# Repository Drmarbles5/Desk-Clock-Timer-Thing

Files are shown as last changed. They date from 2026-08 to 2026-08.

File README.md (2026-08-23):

# Desk Clock Timer

Compact STM32-controlled Bluetooth desk clock powered over USB-C with a [4200 mAh lithium battery](https://www.amazon.ca/4200mah-Rechargeable-Lithium-Replacement-Electronic/dp/B095BP7V1D?th=1) for portability. It connects to Windows/Linux over USB and Bluetooth Low Energy (BLE) for time sync, alarm setup, and media data, and drives a [7.5 inch E-ink display](https://www.waveshare.com/product/7.5inch-e-paper-b.htm) to show the clock, Pomodoro timer, and live Spotify/media information.

<br>
<div align="left">
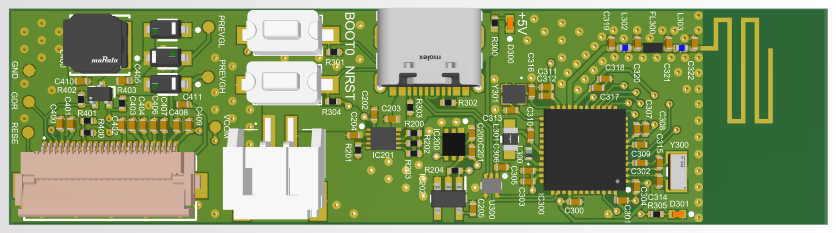
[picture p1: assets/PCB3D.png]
3D
  
  <br>
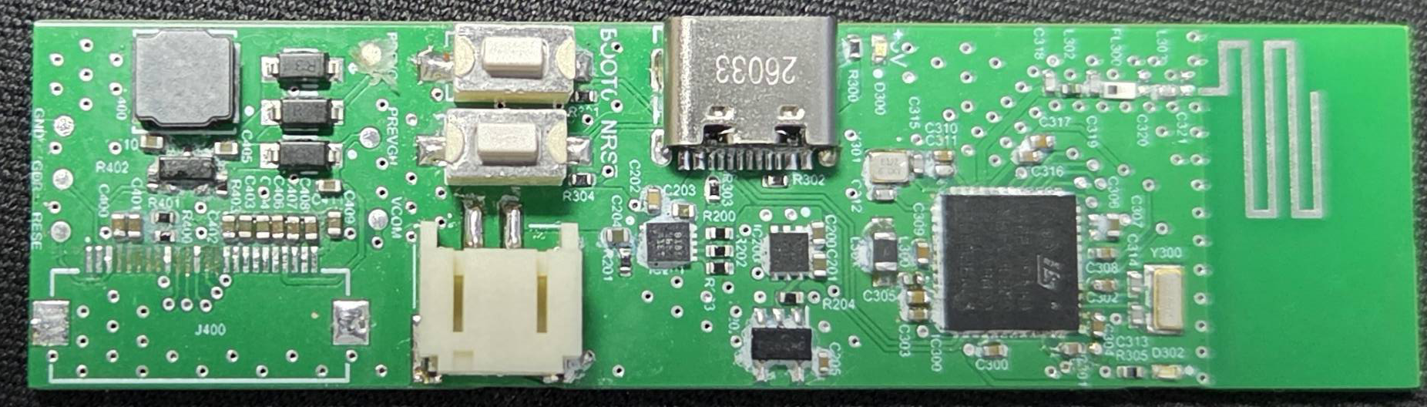
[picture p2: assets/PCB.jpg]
PCB
  
</div>
<br>

Soldering the flat flexible cable connector for display was difficult and a few pads were unfortunately destroyed. Everything will be resoldered on a spare PCB in the near future.

## Status

> Firmware is in progress.

- **Bluetooth Low Energy:** Tested and working. The board advertises as `DCLKTIM` and is discoverable in [nRF Connect](https://www.nordicsemi.com/Products/Development-tools/nRF-Connect-for-Desktop).
- **LED control over BLE:** Working. Writing to the P2P Server characteristic toggles the blue user LED. The payload is one byte:
  - `0x01` → LED on
  - `0x00` → LED off
- **Display & battery:** Not yet tested. The 7.5" E-ink display and the 4200 mAh Li-ion battery have **not** been purchased yet since they were pretty expensive. Planning to get them soon.

## Next Steps

1. Purchase the 7.5" E-ink display and the 4200 mAh Li-ion battery.
2. Wire up and validate the E-ink boost converter (~22 V drive rail) and render the clock/Pomodoro/media UI.
3. Validate USB-C charging and battery behavior.
4. Expand the BLE service beyond the LED demo (time sync, alarm setup, media data).
5. Add enclosure / mechanical design.

## Architecture

```mermaid
flowchart TD
	subgraph Inputs
	I1("`Laptop/Computer (wired)`")
	I2(Bluetooth)
	end

	subgraph PCB
	D1(Power)
	D2(Display)
	D3(Controller)
	end

	subgraph Outputs
	FO1(Clock)
	FO2(Pomodoro Timer)
	FO3(Media Display)
	end

	Inputs --> PCB --> Outputs
```

## Hardware Design Notes

### Layer Stack-Up

The board is 2-layers. Routing is split between the two layers and the empty space is filled with a 
GND pour.

### 2.4 GHz Antenna

The board uses a meander PCB antenna for the 2.4 GHz Bluetooth link. The antenna is designed to 
present a 50 ohm impedance directly to the feedline, so the transceiver sees a clean match across 
the 2400–2480 MHz operating band.

### RF Signal Routing & Integrity

- The RF trace is routed as a coplanar waveguide, with the
  reference ground on the layer directly beneath the trace to maintain the 50 ohm characteristic
  impedance.
- Shielding vias are placed along the RF trace to stitch the top-side ground
  pour to the inner ground plane. These vias form a cage around the trace that reduces
  coupling and keeps the impedance consistent along the run.
- The antenna keep-out zone is clear of copper pours and ground planes to avoid detuning.

### E-Ink Boost Converter

The E-ink display requires a higher drive voltage than the 3.3 V rail. A boost
converter steps the battery/rail voltage up to the display's operating level or about 22V. The boost
switching node and inductor loop are kept tight, short and away from the RF traces to minimize 
EMI and switching losses.

### USB-C Differential Pair

- USB connection is routed as a 90-ohm differential pair for the D+/D− signals. It is length matched 
and tightly coupled.
- USB D+/D− data lines are protected against electrostatic discharge with a TVS diode array
  placed to clamp ESD transients before they reach the transceiver.

## Altium Project

Schematics, layout, and fabrication outputs live in the [`altium/`](altium) folder.
The full schematic set is exported to [`Desk-Clock-Timer.pdf`](altium/Desk-Clock-Timer.pdf), and Gerber/drill files are available under `Project Outputs for Desk-Clock-Timer`.

## Firmware

The controller is an **STM32WB35CCU6A**, a dual-core part: the application runs on the Cortex-M4
(CPU1) and the Bluetooth radio is a prebuilt stack that runs on the Cortex-M0+ (CPU2). The application
alone is not enough — CPU2 must be loaded with the wireless coprocessor firmware before anything
advertises.

### Prerequisites

- [STM32CubeProgrammer](https://www.st.com/en/development-tools/stm32cubeprog.html) — used to flash the
  coprocessor firmware and the application.
- [STM32CubeWB](https://www.st.com/en/embedded-software/stm32cubewb.html) — the STM32WB firmware
  package. The coprocessor binaries live under
  `Projects/STM32WB_Copro_Wireless_Binaries/` after unpacking:
  - `stm32wb3x_FUS_fw.bin` — the FUS (Firmware Upgrade Service) for CPU2.
  - `stm32wb3x_BLE_Stack_fw.bin` — the BLE wireless stack for CPU2.

### One-time coprocessor setup

1. Put the board into DFU mode: **hold the BOOT0 button, press and release RESET, then release BOOT0.**
   This boots the STM32 system bootloader so STM32CubeProgrammer can detect the device over USB.
2. Open STM32CubeProgrammer and connect over **USB**.
3. Flash the **FUS** firmware (`stm32wb3x_FUS_fw.bin`) via the Firmware Upgrade view.
4. Flash the **BLE stack** (`stm32wb3x_BLE_Stack_fw.bin`) the same way.
5. **Activate / start the RF stack** so CPU2 actually runs (the stack can be installed but left stopped;
   it must be started or the device will never advertise).
6. Power-cycle the board. It now boots from flash normally and CPU2 runs the BLE stack.

### Flashing the application

- After the coprocessor firmware is in place, flash **only the application** (the `.elf`/`.bin` built
  from `firmware/DCLKTIM_BLE`).
- **Do not perform a full-chip erase** — that wipes the BLE stack region on CPU2 and the device goes
  silent again. Use "erase only necessary sectors" / program without erase, then reset.

The BLE demo in `firmware/DCLKTIM_BLE/BLE_p2pServer` advertises as `DCLKTIM` and toggles the blue user
LED from the P2P Server characteristic (see [Status](#status)).

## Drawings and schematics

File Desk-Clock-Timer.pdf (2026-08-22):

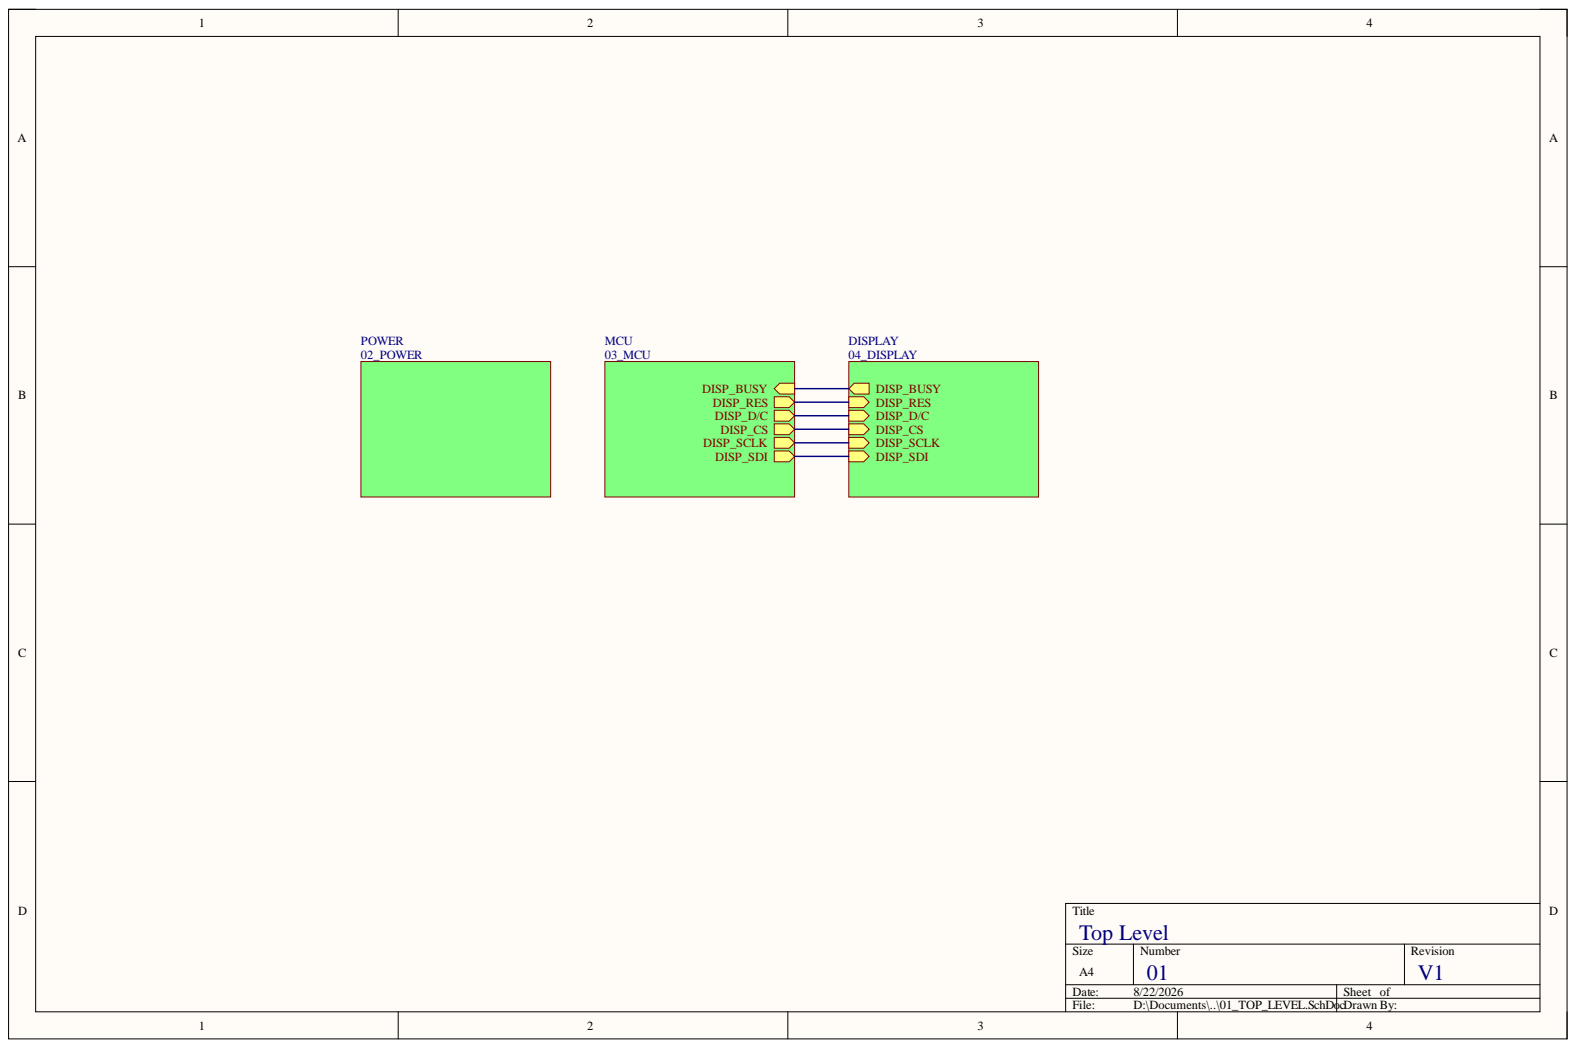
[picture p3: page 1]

Size A4 | Number 01 | Revision V1

Date: 8/22/2026 | Sheet of
File: D:\Documents\..\01_TOP_LEVEL.SchDocDrawn By:

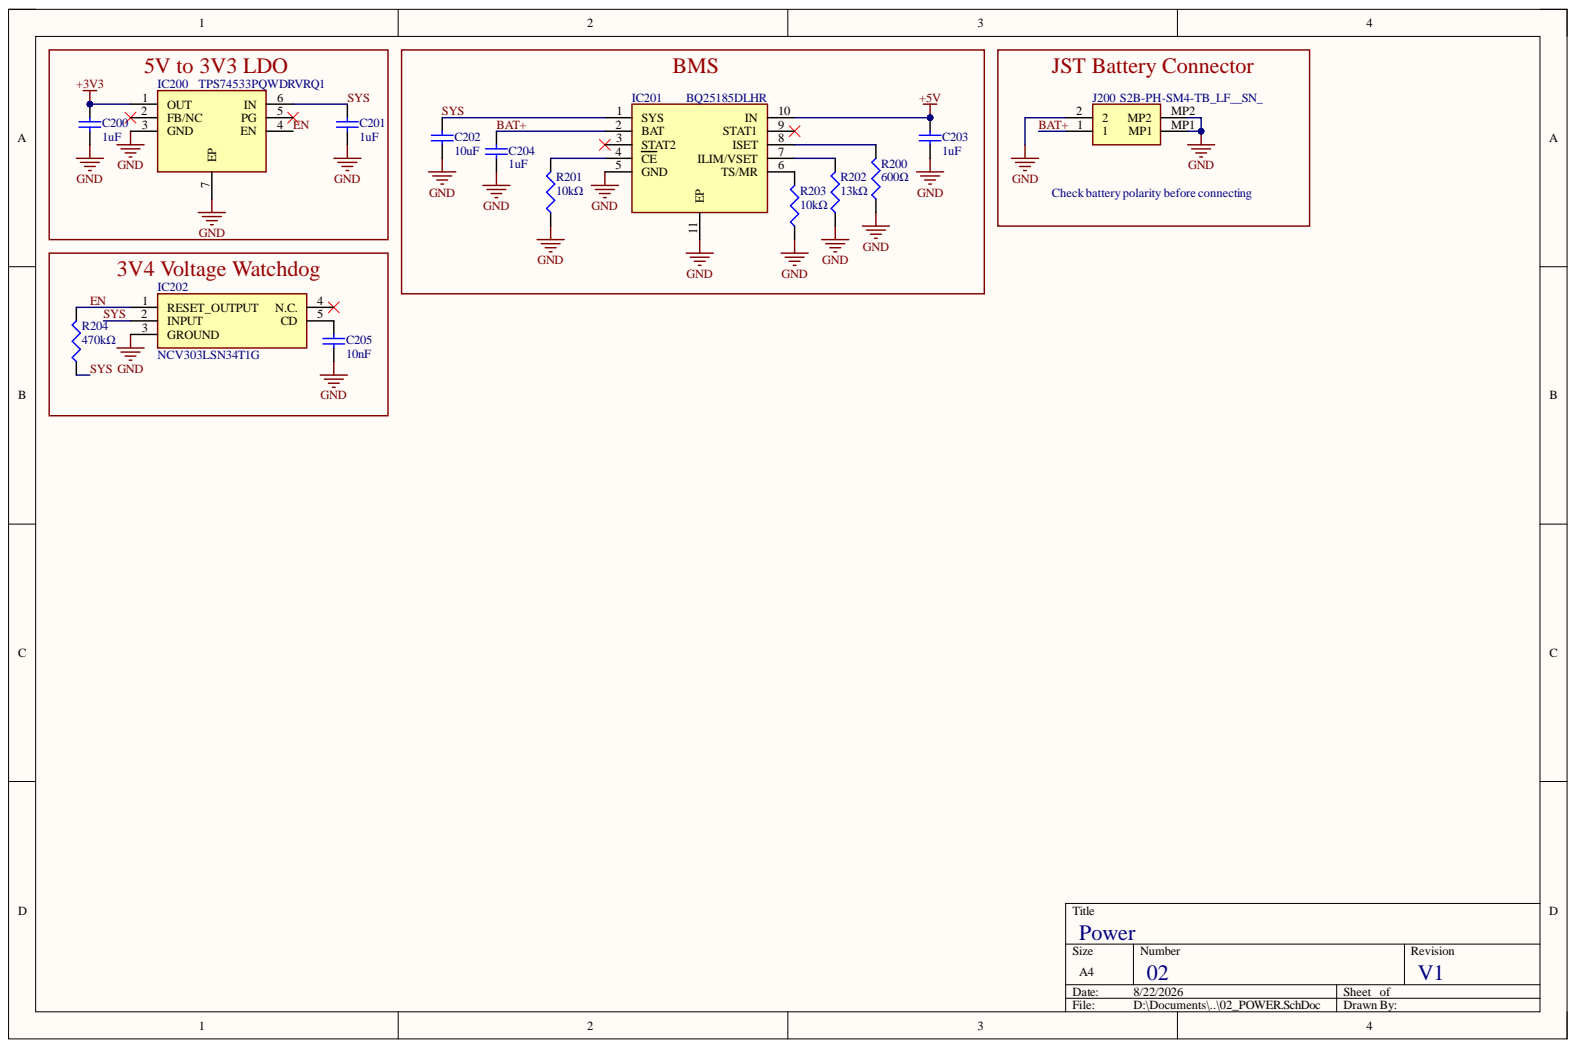
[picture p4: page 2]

JST Battery Connector GND

Siz e A4 | Numb e r 02 | R evisio n V1

Da te : 8/22/202 6 | She et of
File : D:\Documents\. .\02_P O W ER . S c hD o c | Dr awn B y :

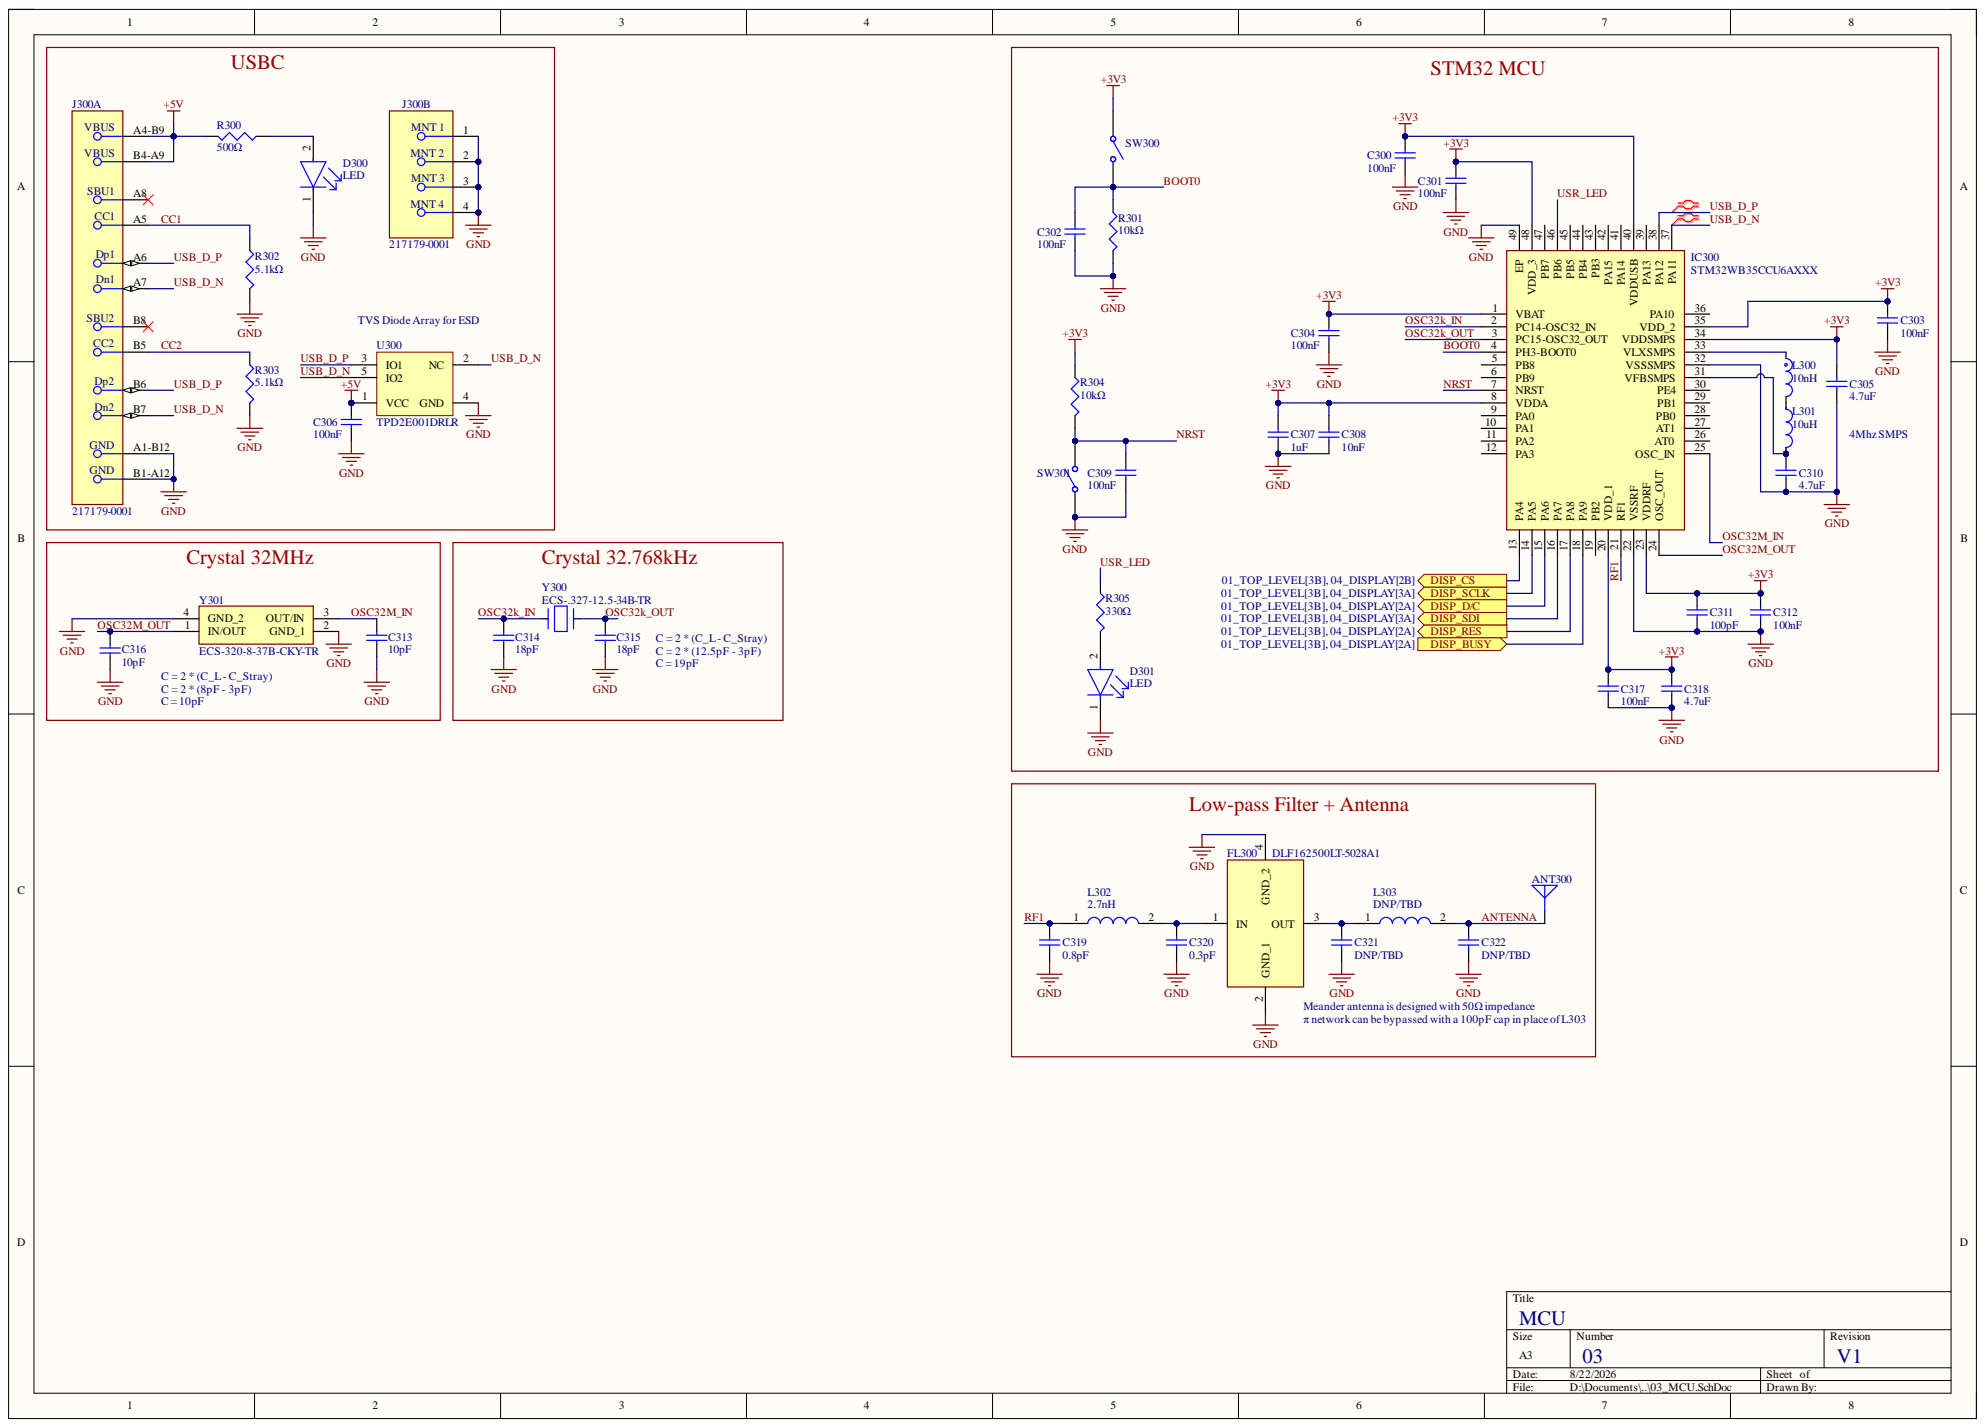
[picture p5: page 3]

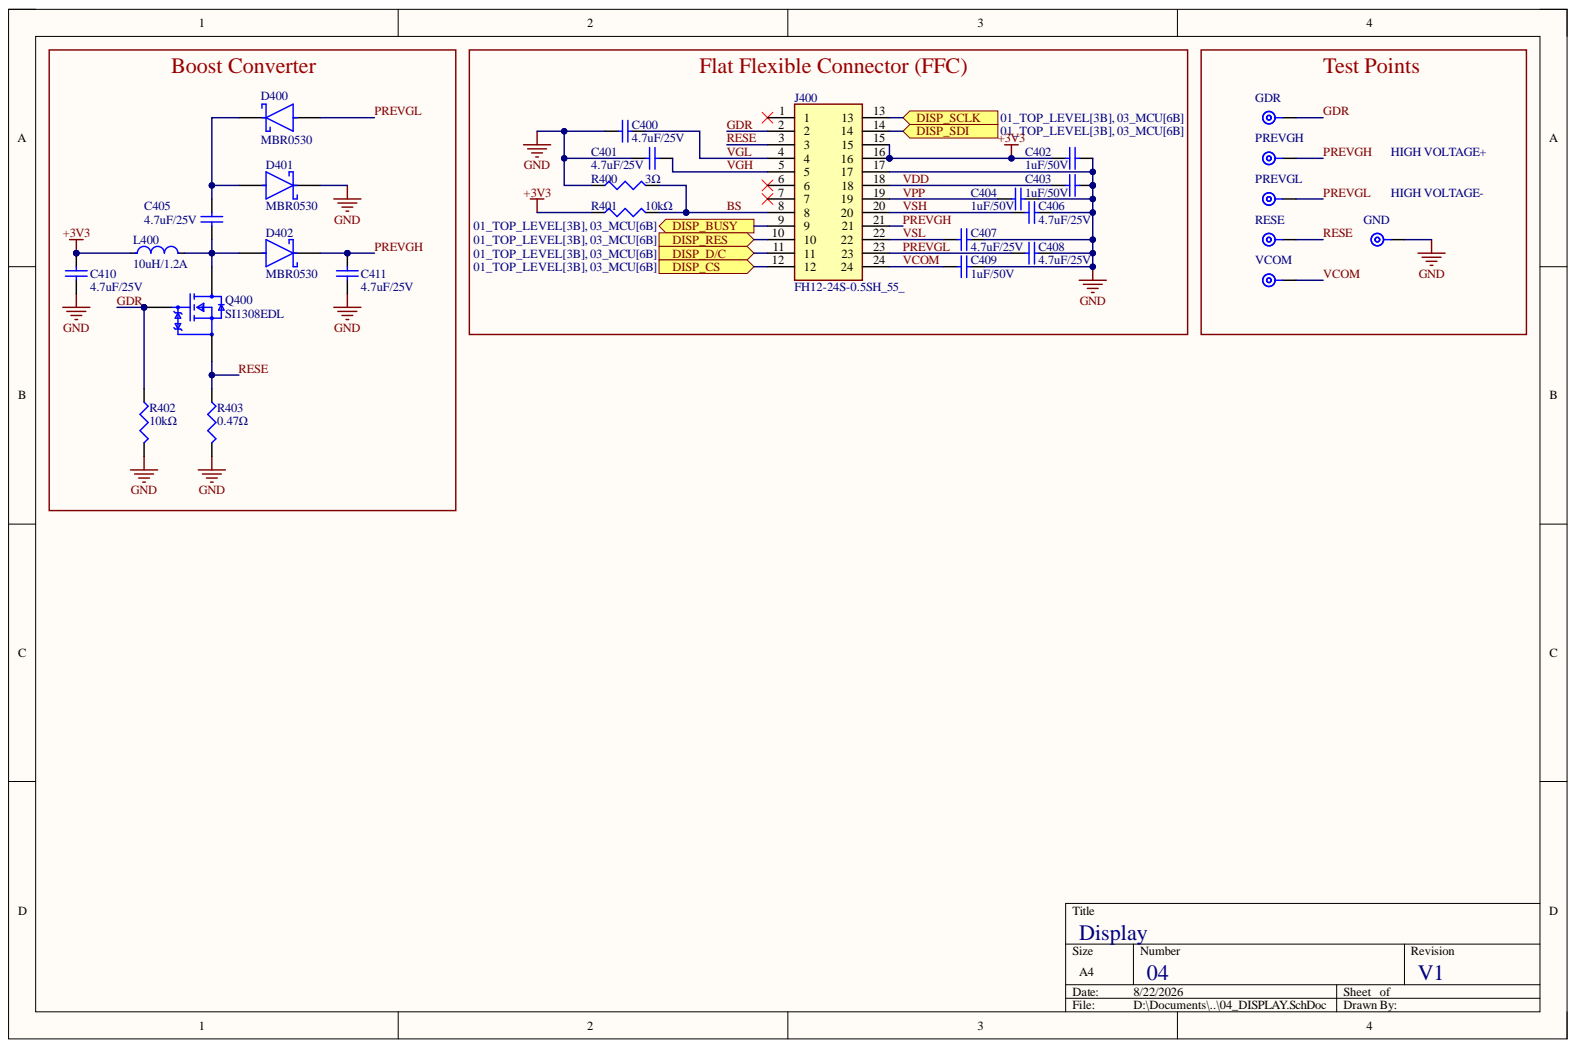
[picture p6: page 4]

P R EV GL | 4.7uF/2 5 V | C40 | 8
VC O M | C40 | 9 | 4.7uF/2 5 V

Siz e A4 | Numb e r 04 | R evisio n V1

Da te : 8/22/202 6 | She et of
File : D:\Documents\. .\04_DI S P LAY. S c hD o c | Dr awn B y :

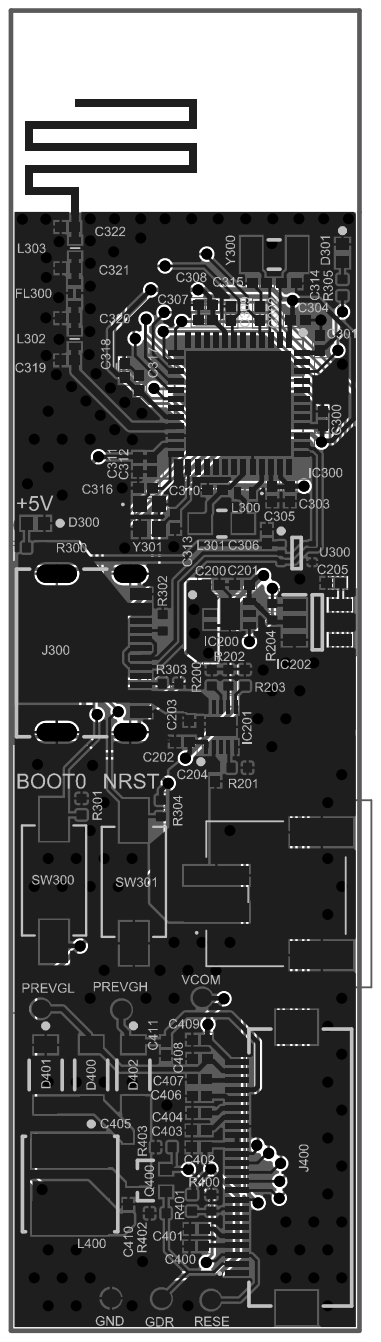
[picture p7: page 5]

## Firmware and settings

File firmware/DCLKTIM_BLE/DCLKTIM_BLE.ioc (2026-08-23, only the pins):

Mcu.UserName=STM32WB35CCUxA
PB6.GPIO_Label=USR_LED
PB6.Signal=GPIO_Output
PC14-OSC32_IN.Signal=RCC_OSC32_IN
PC15-OSC32_OUT.Signal=RCC_OSC32_OUT

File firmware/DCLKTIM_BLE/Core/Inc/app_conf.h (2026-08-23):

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

/* Define to prevent recursive inclusion -------------------------------------*/
#ifndef APP_CONF_H
#define APP_CONF_H

#include "hw.h"
#include "hw_conf.h"
#include "hw_if.h"
#include "ble_bufsize.h"

/******************************************************************************
 * Application Config
 ******************************************************************************/
/**< generic parameters ******************************************************/

/**
 * Define Tx Power
 */
#define CFG_TX_POWER                      (0x18) /* -0.15dBm */

/**
 * Define Advertising parameters
 */
#define CFG_ADV_BD_ADDRESS                (0x7257acd87a6c)

/**
 * Define BD_ADDR type: define proper address. Can only be GAP_PUBLIC_ADDR (0x00) or GAP_STATIC_RANDOM_ADDR (0x01)
 */
#define CFG_IDENTITY_ADDRESS              GAP_PUBLIC_ADDR
/**
 * Define privacy: PRIVACY_DISABLED or PRIVACY_ENABLED
 */
#define CFG_PRIVACY                       PRIVACY_DISABLED

/**
 * Define BLE Address Type
 * Bluetooth address types defined in ble_legacy.h
 * if CFG_PRIVACY equals PRIVACY_DISABLED, CFG_BLE_ADDRESS_TYPE has 2 allowed values: GAP_PUBLIC_ADDR or GAP_STATIC_RANDOM_ADDR
 * if CFG_PRIVACY equals PRIVACY_ENABLED, CFG_BLE_ADDRESS_TYPE has 2 allowed values: GAP_RESOLVABLE_PRIVATE_ADDR or GAP_NON_RESOLVABLE_PRIVATE_ADDR
 */
#define CFG_BLE_ADDRESS_TYPE              GAP_PUBLIC_ADDR

#define CFG_FAST_CONN_ADV_INTERVAL_MIN    (0x80)      /**< 80ms */
#define CFG_FAST_CONN_ADV_INTERVAL_MAX    (0xA0)      /**< 100ms */
#define CFG_LP_CONN_ADV_INTERVAL_MIN      (0x640)     /**< 1s */
#define CFG_LP_CONN_ADV_INTERVAL_MAX      (0xFA0)     /**< 2.5s */
/**
 * Define IO Authentication
 */
#define CFG_BONDING_MODE                 (1)
#define CFG_ENCRYPTION_KEY_SIZE_MAX      (16)
#define CFG_ENCRYPTION_KEY_SIZE_MIN      (8)

/**
 * Define IO capabilities
 */
#define CFG_IO_CAPABILITY_DISPLAY_ONLY        (0x00)
#define CFG_IO_CAPABILITY_DISPLAY_YES_NO      (0x01)
#define CFG_IO_CAPABILITY_KEYBOARD_ONLY       (0x02)
#define CFG_IO_CAPABILITY_NO_INPUT_NO_OUTPUT  (0x03)
#define CFG_IO_CAPABILITY_KEYBOARD_DISPLAY    (0x04)

#define CFG_IO_CAPABILITY                     CFG_IO_CAPABILITY_DISPLAY_YES_NO

/**
 * Define MITM modes
 */
#define CFG_MITM_PROTECTION_NOT_REQUIRED      (0x00)
#define CFG_MITM_PROTECTION_REQUIRED          (0x01)

#define CFG_MITM_PROTECTION                   CFG_MITM_PROTECTION_REQUIRED

/**
 * Define Secure Connections Support
 */
#define CFG_SECURE_NOT_SUPPORTED              (0x00)
#define CFG_SECURE_OPTIONAL                   (0x01)
#define CFG_SECURE_MANDATORY                  (0x02)

#define CFG_SC_SUPPORT                        CFG_SECURE_OPTIONAL

/**
 * Define Keypress Notification Support
 */
#define CFG_KEYPRESS_NOT_SUPPORTED            (0x00)
#define CFG_KEYPRESS_SUPPORTED                (0x01)

#define CFG_KEYPRESS_NOTIFICATION_SUPPORT     CFG_KEYPRESS_NOT_SUPPORTED

/**
 * Numeric Comparison Answers
 */
#define YES (0x01)
#define NO  (0x00)

/**
 * Device name configuration for Generic Access Service
 */
#define CFG_GAP_DEVICE_NAME             "TEMPLATE"
#define CFG_GAP_DEVICE_NAME_LENGTH      (8)

/**
 * Define PHY
 */
#define ALL_PHYS_PREFERENCE                             0x00
#define RX_2M_PREFERRED                                 0x02
#define TX_2M_PREFERRED                                 0x02
#define TX_1M                                           0x01
#define TX_2M                                           0x02
#define RX_1M                                           0x01
#define RX_2M                                           0x02

/**
*   Identity root key used to derive IRK and DHK(Legacy)
*/
#define CFG_BLE_IR     {0x12, 0x34, 0x56, 0x78, 0x9A, 0xBC, 0xDE, 0xF0, 0x12, 0x34, 0x56, 0x78, 0x9A, 0xBC, 0xDE, 0xF0}

/**
* Encryption root key used to derive LTK(Legacy) and CSRK
*/
#define CFG_BLE_ER     {0xFE, 0xDC, 0xBA, 0x09, 0x87, 0x65, 0x43, 0x21, 0xFE, 0xDC, 0xBA, 0x09, 0x87, 0x65, 0x43, 0x21}

/**
 * SMPS supply
 * SMPS not used when Set to 0
 * SMPS used when Set to 1
 */
#define CFG_USE_SMPS    0

/**< specific parameters */
/*****************************************************/

#define P2P_SERVER1    1    /*1 = Device is Peripherique*/
#define P2P_SERVER2    0
#define P2P_SERVER3    0
#define P2P_SERVER4    0
#define P2P_SERVER5    0
#define P2P_SERVER6    0

#define CFG_DEV_ID_P2P_SERVER1                  (0x83)
#define CFG_DEV_ID_P2P_SERVER2                  (0x84)
#define CFG_DEV_ID_P2P_SERVER3                  (0x87)
#define CFG_DEV_ID_P2P_SERVER4                  (0x88)
#define CFG_DEV_ID_P2P_SERVER5                  (0x89)
#define CFG_DEV_ID_P2P_SERVER6                  (0x8A)
#define CFG_DEV_ID_P2P_ROUTER                   (0x85)

#define  RADIO_ACTIVITY_EVENT   1          /* 1 for OOB Demo */

/**
* AD Element - Group B Feature
*/
/* LSB - First Byte */
#define CFG_FEATURE_THREAD_SWITCH               (0x40)

/* LSB - Second Byte */
#define CFG_FEATURE_OTA_REBOOT                  (0x20)

#define CONN_L(x) ((int)((x)/0.625f))
#define CONN_P(x) ((int)((x)/1.25f))

  /*  L2CAP Connection Update request parameters used for test only with smart Phone */
#define L2CAP_REQUEST_NEW_CONN_PARAM             1

#define L2CAP_INTERVAL_MIN              CONN_P(1000) /* 1s */
#define L2CAP_INTERVAL_MAX              CONN_P(1000) /* 1s */
#define L2CAP_PERIPHERAL_LATENCY             0x0000
#define L2CAP_TIMEOUT_MULTIPLIER        0x1F4

/******************************************************************************
 * BLE Stack
 ******************************************************************************/
/**
 * Maximum number of simultaneous connections that the device will support.
 * Valid values are from 1 to 8
 */
#define CFG_BLE_NUM_LINK            2

/**
 * Maximum number of Services that can be stored in the GATT database.
 * Note that the GAP and GATT services are automatically added so this parameter should be 2 plus the number of user services
 */
#define CFG_BLE_NUM_GATT_SERVICES   8

/**
 * Maximum number of Attributes
 * (i.e. the number of characteristic + the number of characteristic values + the number of descriptors, excluding the services)
 * that can be stored in the GATT database.
 * Note that certain characteristics and relative descriptors are added automatically during device initialization
 * so this parameters should be 9 plus the number of user Attributes
 */
#define CFG_BLE_NUM_GATT_ATTRIBUTES 68

/**
 * Maximum supported ATT_MTU size
 * This parameter is ignored by the CPU2 when CFG_BLE_OPTIONS has SHCI_C2_BLE_INIT_OPTIONS_LL_ONLY flag set
 */
#define CFG_BLE_MAX_ATT_MTU             (156)
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

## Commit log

2026-07-18 attempt to add altium proj
    [Desk-Clock-Timer.PrjPcb, Sheet1.SchDoc]
2026-07-21 add power stuff
    [Sheet1.SchDoc]
2026-07-21 update file name
    [01_POWER.SchDoc]
2026-07-21 add top level file
    [01_POWER.SchDoc]
2026-07-21 add display file to version control
    [04_DISPLAY.SchDoc]
2026-07-21 update again
    [01_TOP_LEVEL.SchDoc, 02_POWER.SchDoc, 03_MCU.SchDoc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]
2026-07-21 fix documentation in display sheet
    [04_DISPLAY.SchDoc]
2026-07-21 added power supply scheme of microcontroller, added crystal oscillator, connected microcontroller to display (SPI).
    [03_MCU.SchDoc, 04_DISPLAY.SchDoc]
2026-07-21 new list of things to do
    [03_MCU.SchDoc]
2026-07-22 update to 3v3
    [04_DISPLAY.SchDoc]
2026-07-22 Changed LDO to be 3V3. Added voltage monitor to shut off LDO before dropout point
    [02_POWER.SchDoc]
2026-07-22 wired usbc, wired boot and restart pins, wired header.
    [03_MCU.SchDoc]
2026-07-22 format mcu sheet
    [03_MCU.SchDoc]
2026-07-22 Added 50 Ohm matching network.
    [03_MCU.SchDoc]
2026-07-22 add antenna and update to do
    [01_TOP_LEVEL.SchDoc, 03_MCU.SchDoc, Desk-Clock-Timer.PrjPcb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]
2026-07-22 add 32kHz crystal, add nreset protection diode, wire vddusb
    [03_MCU.SchDoc, Schlib1.SchLib]
2026-07-23 switch components to 0402, annotate entire project
    [01_TOP_LEVEL.SchDoc, 02_POWER.SchDoc, 03_MCU.SchDoc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]
2026-07-23 remove fork in antenna path, clean up comments
    [03_MCU.SchDoc]
2026-07-23 update comments in mcu sheet
    [03_MCU.SchDoc]
2026-07-23 Added Components to Schlib
    [02_POWER.SchDoc, PcbLib1.PcbLib, Schlib1.SchLib]
2026-07-23 update symbols to use project pcblib
    [02_POWER.SchDoc, 03_MCU.SchDoc, 04_DISPLAY.SchDoc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]
2026-07-23 Fixed LDO Schematic
    [02_POWER.SchDoc, PcbLib1.PcbLib, Schlib1.SchLib]
2026-07-23 annotate LDO
    [02_POWER.SchDoc]
2026-07-23 change 3V3 rail to +3V3
    [02_POWER.SchDoc]
2026-07-23 add missing inductor footprint and pcbdoc
    [03_MCU.SchDoc, Desk-Clock-Timer.PrjPcb, PCB1.PcbDoc]
2026-07-23 add missing inductor footprint
    [03_MCU.SchDoc]
2026-07-23 start pcb layout
    [02_POWER.SchDoc, 03_MCU.SchDoc, PCB1.PcbDoc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]
2026-07-24 layout v1
    [02_POWER.SchDoc, 03_MCU.SchDoc, 04_DISPLAY.SchDoc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]
2026-07-24 define board shape
    [PCB1.PcbDoc]
2026-07-24 move caps to make space for RF trace
    [PCB1.PcbDoc]
2026-07-25 move silkscreen labels
    [PCB1.PcbDoc]
2026-07-26 bunch of routing
    [03_MCU.SchDoc, 04_DISPLAY.SchDoc, PCB1.PcbDoc]
2026-07-26 finish routing
    [04_DISPLAY.SchDoc, Desk-Clock-Timer.PrjPcb, PCB1.PcbDoc]
2026-07-27 fix mechanical outline
    [PCB1.PcbDoc]
2026-07-27 repour polygons
    [PCB1.PcbDoc]
2026-07-27 fix via clipping connector pad
    [PCB1.PcbDoc]
2026-08-01 update cap voltage ratings in display sheet, generate fabrication outputs, generate pdf
    [01_TOP_LEVEL.SchDoc, 02_POWER.SchDoc, 03_MCU.SchDoc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]
2026-08-01 regenerate fabrication outputs
    [PCB1.GBL, PCB1.GBO, PCB1.GBP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]
2026-08-01 fix stitching vias
    [PCB1.GBL, PCB1.GBO, PCB1.GBP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]
2026-08-10 update pdf
    [Desk-Clock-Timer.PrjPcb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]
2026-08-10 fix readme flowchart
2026-08-22 add esd protection to usb data lines, fix component spacing for easier solding
    [03_MCU.SchDoc, 04_DISPLAY.SchDoc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]
2026-08-22 update prjpcb
    [Desk-Clock-Timer.PrjPcb]
2026-08-23 add pcb images, update readme

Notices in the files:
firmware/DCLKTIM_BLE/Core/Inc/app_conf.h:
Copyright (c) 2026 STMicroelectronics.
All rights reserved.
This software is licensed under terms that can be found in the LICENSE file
